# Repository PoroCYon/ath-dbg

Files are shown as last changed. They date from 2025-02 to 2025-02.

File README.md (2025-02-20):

# ath-dbg

Adapter and level shifter PCB for debugging the Xtensa CPU in WiFi modules for
the Nintendo DSi.

## Usage

Mount a module on J1. If desired, also use J4 to connect the UART and ERST
signals to the corresponding testpoints on the module. This latter thing will
require some soldering.

Either use the external connectors (J2/J3, J5, J6) or solder a Raspberry Pico
directly to the pin holes present for it.

Some software will still be required to actually do JTAG debugging of the Xtensa
Cpu from a computer. Figuring out how exactly this could be made possible is
the reaosn I built this to begin with.

### Raspberry Pico pinouts

* `GP00`: UART RP to Ath/DWM (R2A)
* `GP01`: UART Ath/DWM to RP (A2R)
* `GP02`: JTAG.ERST (debug CPU reset extension)
* `GP03`: JTAG.TRST
* `GP04`: ~{WIFI_RST}
* `GP05`: SPI.~{WP}
* `GP06`: nSEL_ATH (0=Ath/DWM/TWL, 1=NTR wifi)
* `GP07`: 32 kHz clock to DWM
* `GP08`: SPI.CIPO
* `GP09`: SPI.~{CS}
* `GP10`: SPI.SCK
* `GP11`: SPI.COPI
* `GP12`: JTAG.TDO
* `GP13`: JTAG.TCK
* `GP14`: JTAG.TDI
* `GP15`: JTAG.TMS
* `GP16`: SDIO.CLK
* `GP17`: SDIO.D0
* `GP18`: SDIO.D1
* `GP19`: SDIO.D2
* `GP20`: SDIO.D3
* `GP21`: SDIO.CMD
* `GP22`: ATH_TX_H
* `GP26`: nTWLRST (DSi system reset)
* `GP27`: nDETECT (0=DWM inserted)
* `GP28`: JTAG.CPURST (CPU reset if JTAG.ERST=1 on boot. else ~{WIFI_RST} is the reset)

## Bill of Materials

| Reference | Value  | Footprint | Notes |
|:--- |:--- |:--- |:----- |
| C1, C3 | 1 uF | 0603 | 1V8 LDO cap |
| C3-C8 | 100 nF | 0603 | decoupling caps |
| J1 | Molex SlimStack 52991-0508 | | WiFi module connector. must be this exact part number. |
| J2 | 1x9-pin header | 2.54mm pitch | |
| J3 | 10-pin Cortex Debug connector | 1.27mm | dual SMD/THT footprint |
| J4 | 1x6-pin header | 2.54mm pitch | |
| J5 | 1x8-pin header | 2.54mm pitch | |
| J6 | 1x4-pin header | 2.54mm pitch | |
| R1-R6 | 22 Ohm | 0603 | |
| R7-R17 | 47 kOhm | 0603 | |
| U1 | Raspberry Pico | Raspberry Pico | |
| U2 | 3.3V-&gt;1.8V LDO | SOT-23-5  | TI TLV70018DDC, Diodes AP7343D-18W5-7 |
| U3-U5 | 3.3V&lt;-&gt;1.8V level shifter | TSSOP-14 | TI TXU0304, Nexperia NXU0304 |

## Dependencies

RP2040 and Raspberry Pico symbols and footprints from [here
](https://github.com/ncarandini/KiCad-RP-Pico).

## License

[CERN-OHL-S v2](./LICENSE)

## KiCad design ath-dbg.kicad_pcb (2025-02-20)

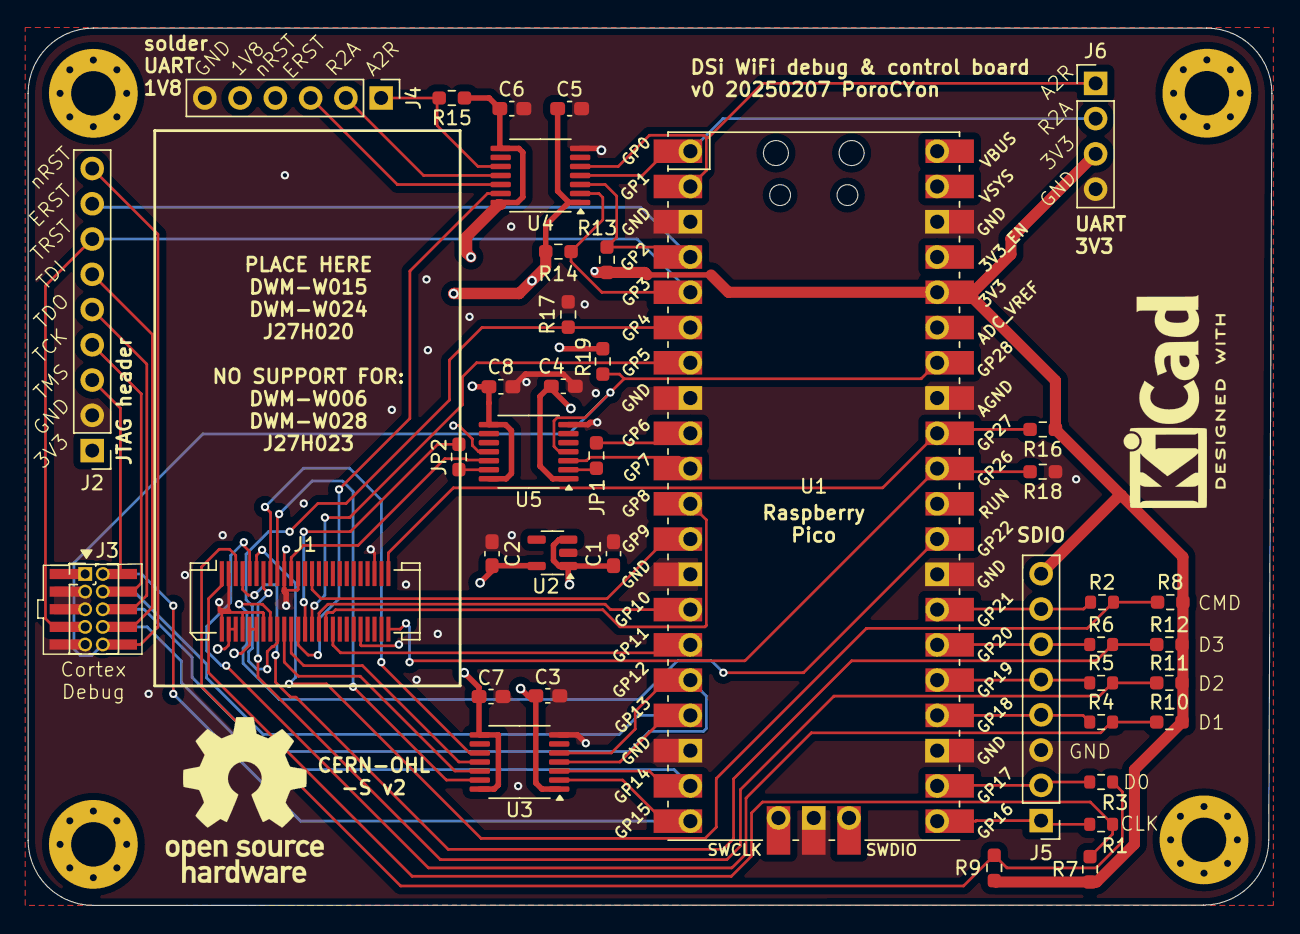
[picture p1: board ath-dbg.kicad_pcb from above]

Board: 4 copper layers, 89.6 x 63.2 mm, 45 parts (0 on the bottom side), 48 nets.

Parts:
C1, C2: 1u; C_0603_1608Metric_Pad1.08x0.95mm_HandSolder
C3, C4, C5, C6, C7, C8: 100n; C_0603_1608Metric_Pad1.08x0.95mm_HandSolder
H1, H2, H3, H4: MountingHole; MountingHole_3.2mm_M3_Pad_Via
J1: TWL_WifiConn_Rcpt; Molex_SlimStack_52991-0508_2x25_P0.50mm_Vertical
J2: Conn_01x09; PinHeader_1x09_P2.54mm_Vertical
J3: CortexDbgConn; PinHeader_2x05_P1.27mm_Vertical
J4: Conn_01x05; PinHeader_1x06_P2.54mm_Vertical
J5: Conn_01x08; PinHeader_1x08_P2.54mm_Vertical
J6: Conn_01x04; PinHeader_1x04_P2.54mm_Vertical
J10: CortexDbgConn SMD; PinHeader_2x05_P1.27mm_Vertical_SMD
JP1, JP2: SolderJumper_2_Open; R_0603_1608Metric_Pad0.98x0.95mm_HandSolder
R1, R2, R3, R4, R5, R6: 22; R_0603_1608Metric
R7, R8, R9, R10, R11, R12, R13, R14, R15, R16, R17, R18, R19: 47k; R_0603_1608Metric_Pad0.98x0.95mm_HandSolder
U1: Pico; RPi_Pico_SMD_TH
U2: TLV70018DDC; SOT-23-5
U3, U4, U5: TXU0304; TSSOP-14_4.4x5mm_P0.65mm

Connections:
+1V8: C2.1, C6.1, C7.1, C8.1, J1.4 (VDD18), J1.6 (VDD18), J4.5, R15.1, U2.5 (OUT), U3.8 (OE), U3.14 (V_{CCB}), U4.8 (OE), U4.14 (V_{CCB}), U5.8 (OE), U5.14 (V_{CCB})
+3V3: C1.1, C3.1, C4.1, C5.1, J1.10 (VDD33), J1.12 (VDD33), J2.1, J3.1, J5.8, J6.3, J10.1, R7.2, R8.2, R9.2, R10.2, R11.2, R12.2, R13.1, R14.1, R16.1, R19.1, U1.36 (3V3), U2.1 (IN), U2.3 (EN), U3.1 (V_{CCA}), U4.1 (V_{CCA}), U5.1 (V_{CCA})
/CLK': J5.1, R1.1, U1.21 (GPIO16)
/CMD': J5.7, R2.1, U1.27 (GPIO21)
/D0': J5.2, R3.1, U1.22 (GPIO17)
/D1': J5.4, R4.1, U1.24 (GPIO18)
/D2': J5.5, R5.1, U1.25 (GPIO19)
/D3': J5.6, R6.1, U1.26 (GPIO20)
ATH_TX_H: J1.16 (ATH_TX_H), U1.29 (GPIO22)
CIPO: J1.32 (SPI_CIPO), U1.11 (GPIO8)
CLK: J1.1 (SDIO_CLK), R1.2, R7.1
CLK32K_18: J1.21 (RTC_FOUT), U5.12 (B2Y)
CLK32K_33: U1.10 (GPIO7), U5.3 (A2)
CMD: J1.11 (SDIO_CMD), R2.2, R8.1
COPI: J1.34 (SPI_COPI), U1.15 (GPIO11)
D0: J1.5 (SDIO_DAT0), R3.2, R9.1
D1: J1.9 (SDIO_DAT1), R4.2, R10.1
D2: J1.13 (SDIO_DAT2), R5.2, R11.1
D3: J1.7 (SDIO_DAT3), R6.2, R12.1
DET_TWL: J1.49, R16.2, U1.32 (GPIO27_ADC1)
GND: C1.2, C2.2, C3.2, C4.2, C5.2, C6.2, C7.2, C8.2, J1.2 (GND), J1.3 (GND), J1.8 (GND), J1.14 (GND), J1.19 (GND), J1.23 (GND), J1.42 (GND), J1.45 (GND), J2.2, J3.3, J3.5, J3.9, J4.6, J5.3, J6.4, J10.3, J10.5, J10.9, R17.1, R18.1, U1.3 (GND), U1.8 (GND), U1.13 (GND), U1.18 (GND), U1.23 (GND), U1.28 (GND), U1.33 (AGND), U1.38 (GND), U1.42 (GND), U2.2 (GND), U3.7 (GND), U4.7 (GND), U5.7 (GND)
JTAG18.CPURST: J4.4, U5.11 (B3Y)
JTAG18.ERST: J4.3, U4.12 (B2Y)
JTAG18.TCK: J1.22 (JTAG_TCK), U3.11 (B3Y)
JTAG18.TDI: J1.20 (JTAG_TDI), U3.12 (B2Y)
JTAG18.TDO: J1.15 (JTAG_TDO), U3.10 (B4)
JTAG18.TMS: J1.17 (JTAG_TMS), U3.13 (B1Y)
JTAG18.~TRST: J1.24 (JTAG_~TRST), U4.13 (B1Y)
JTAG33.CPURST: J2.9, J3.10, J10.10, R19.2, U1.34 (GPIO28_ADC2), U5.4 (A3)
JTAG33.ERST: J2.8, R13.2, U1.4 (GPIO2), U4.3 (A2)
JTAG33.TCK: J2.4, J3.4, J10.4, U1.17 (GPIO13), U3.4 (A3)
JTAG33.TDI: J2.6, J3.8, J10.8, U1.19 (GPIO14), U3.3 (A2)
JTAG33.TDO: J2.5, J3.6, J10.6, U1.16 (GPIO12), U3.5 (A4Y)
JTAG33.TMS: J2.3, J3.2, J10.2, U1.20 (GPIO15), U3.2 (A1)
JTAG33.~TRST: J2.7, J3.7, J10.7, R14.2, U1.5 (GPIO3), U4.2 (A1)
unnamed: JP1.2 (B), U5.2 (A1)
unnamed: JP2.1 (A), U5.13 (B1Y)
SCK: J1.30 (SPI_SCK), U1.14 (GPIO10)
UART18.ATH2RP: J4.1, R15.2, U4.10 (B4)
UART18.RP2ATH: J4.2, U4.11 (B3Y)
UART33.ATH2RP: J6.1, U1.2 (GPIO1), U4.5 (A4Y)
UART33.RP2ATH: J6.2, U1.1 (GPIO0), U4.4 (A3)
~CS: J1.27 (SPI_~CS2), U1.12 (GPIO9)
~SEL_ATH_18: J1.26 (~SEL_ATH), JP2.2 (B)
~SEL_ATH_33: JP1.1 (A), U1.9 (GPIO6)
~TWLRST: J1.50 (RESET), R18.2, U1.31 (GPIO26_ADC0)
~WIFI_RST: J1.18 (~WIFI_RST), R17.2, U1.6 (GPIO4)
~WP: J1.28 (FLASH_~WP), U1.7 (GPIO5)

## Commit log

2025-02-07 reset stuff
    [ath-dbg.kicad_pcb, ath-dbg.kicad_sch]
2025-02-20 fix typo in readme
    [ath-dbg.kicad_pcb]

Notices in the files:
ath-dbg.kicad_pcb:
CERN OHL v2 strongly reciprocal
